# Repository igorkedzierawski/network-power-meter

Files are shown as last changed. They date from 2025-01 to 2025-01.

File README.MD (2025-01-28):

# Power Panel with Built-in Energy Analyzer based on ESP32

## Project Description
This project was realized as part of my engineering thesis at the Warsaw University of Technology. The device measures the voltage and current of connected devices. The measured data is transmitted from the device to a web application, where it is analyzed. In real-time, the application processes the gathered data and presents the electrical parameters and visualizations of the voltage and current waveforms to the user.

The device is controlled via the web application – measurements are read, results are visualized, and analysis is performed there. The operation is intuitive:
1. Connect the device to power.
2. Connect to it via Wi-Fi.
3. Connect the device you want to test.
4. Measurement results and analysis are available in the web interface.

The final result of the project is a ready-to-use IoT device.

## System Architecture
The project consists of three main components:

1. **Meter Controller** (ESP32 + measurement circuit) – responsible for Wi-Fi connectivity, menu handling, and managing the measurement circuit.
2. **Backend (ESP32 HTTP/WebSocket Server)** – allows control of the device via HTTP endpoints and fast transmission of measurement results via WebSocket.
3. **Frontend (Angular)** – the web application responsible for controlling the meter, analyzing the received data, and presenting both calculated values and waveform visualizations.
4. **PCB Design** – connects all physical components of the meter control board.

## Web Interface Functionality
- **View Electrical Parameters and Harmonic Analysis** – real-time display of measurement results for voltage, current, and power, as well as THD coefficient and harmonic analysis.
- **Waveform Visualization** – shows measured waveforms on a virtual oscilloscope.
- **Measurement Channel and System Parameter Configuration** – allows setting different channels and adjusting device parameters.
- **Trigger Selection and Analysis Window Width Adjustment** – stabilizes waveform drawing and adjusts measurement precision.
- **Meter Calibration** – adjusts calibration coefficients and selects network frequency (50/60Hz).

## Repository Structure
- **smm-esp32** – Source code for ESP32 (C, ESP-IDF)
- **smm-frontend** – Web application (Angular, TypeScript)
- **smm-pcb** – PCB design (KiCad)

## Device Photos

### Final Device
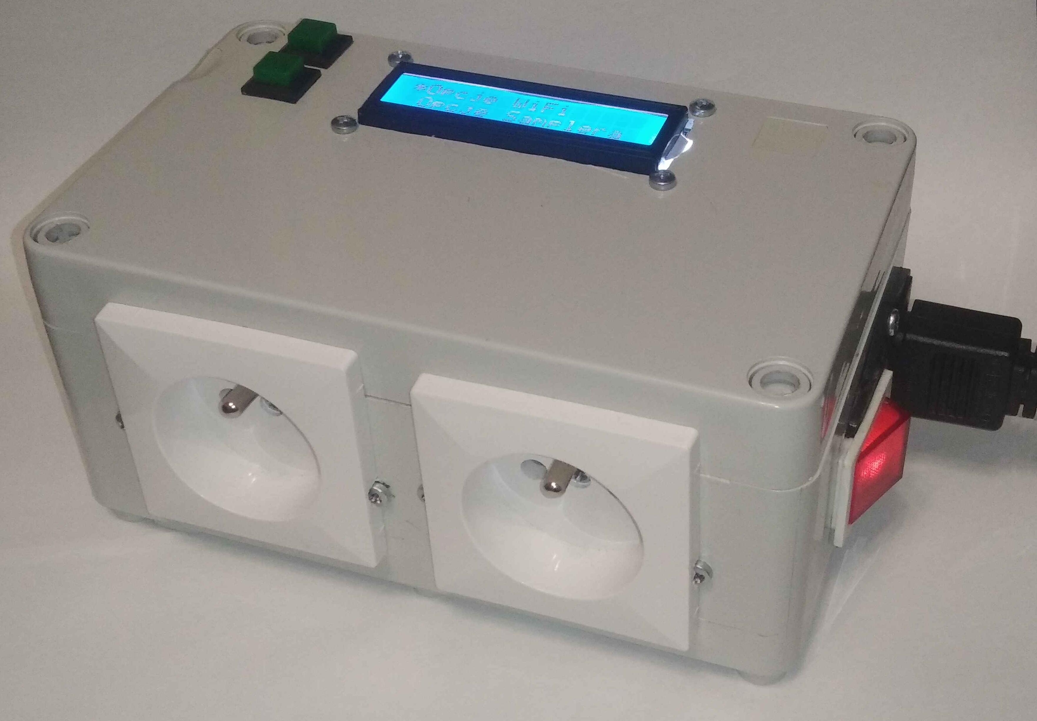
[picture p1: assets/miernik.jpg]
Meter


### Meter Control Board PCB
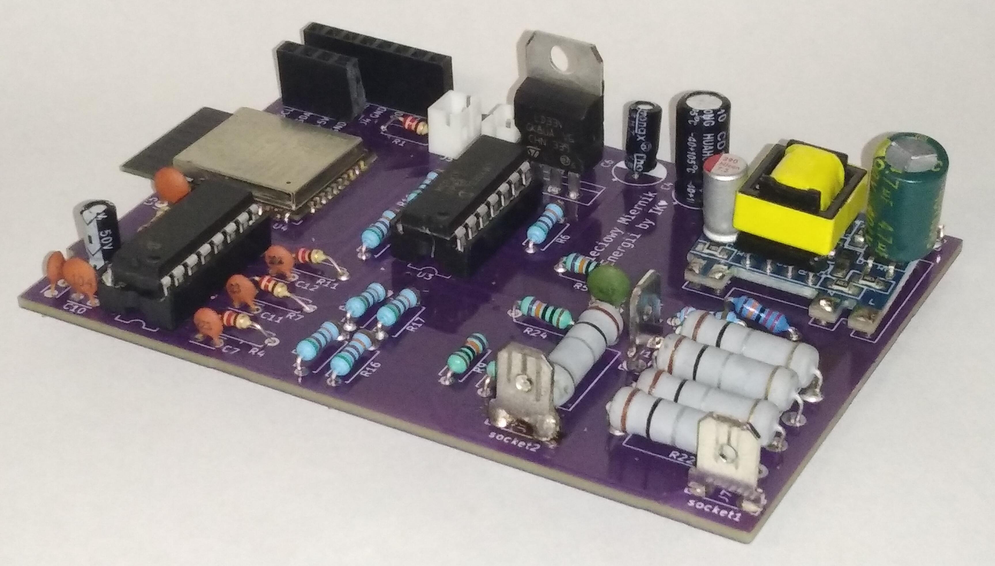
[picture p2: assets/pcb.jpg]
PCB


### Web Interface in Use
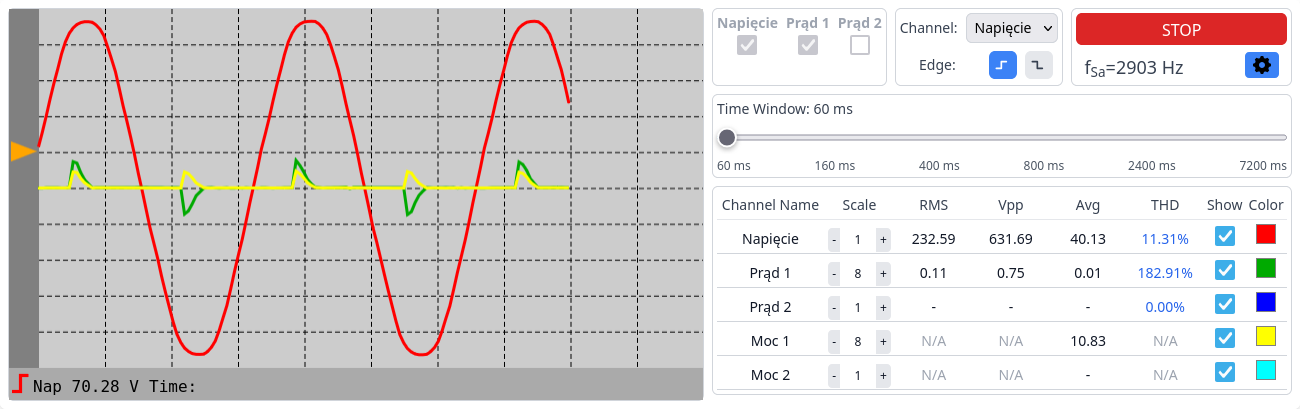
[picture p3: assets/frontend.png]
Interface


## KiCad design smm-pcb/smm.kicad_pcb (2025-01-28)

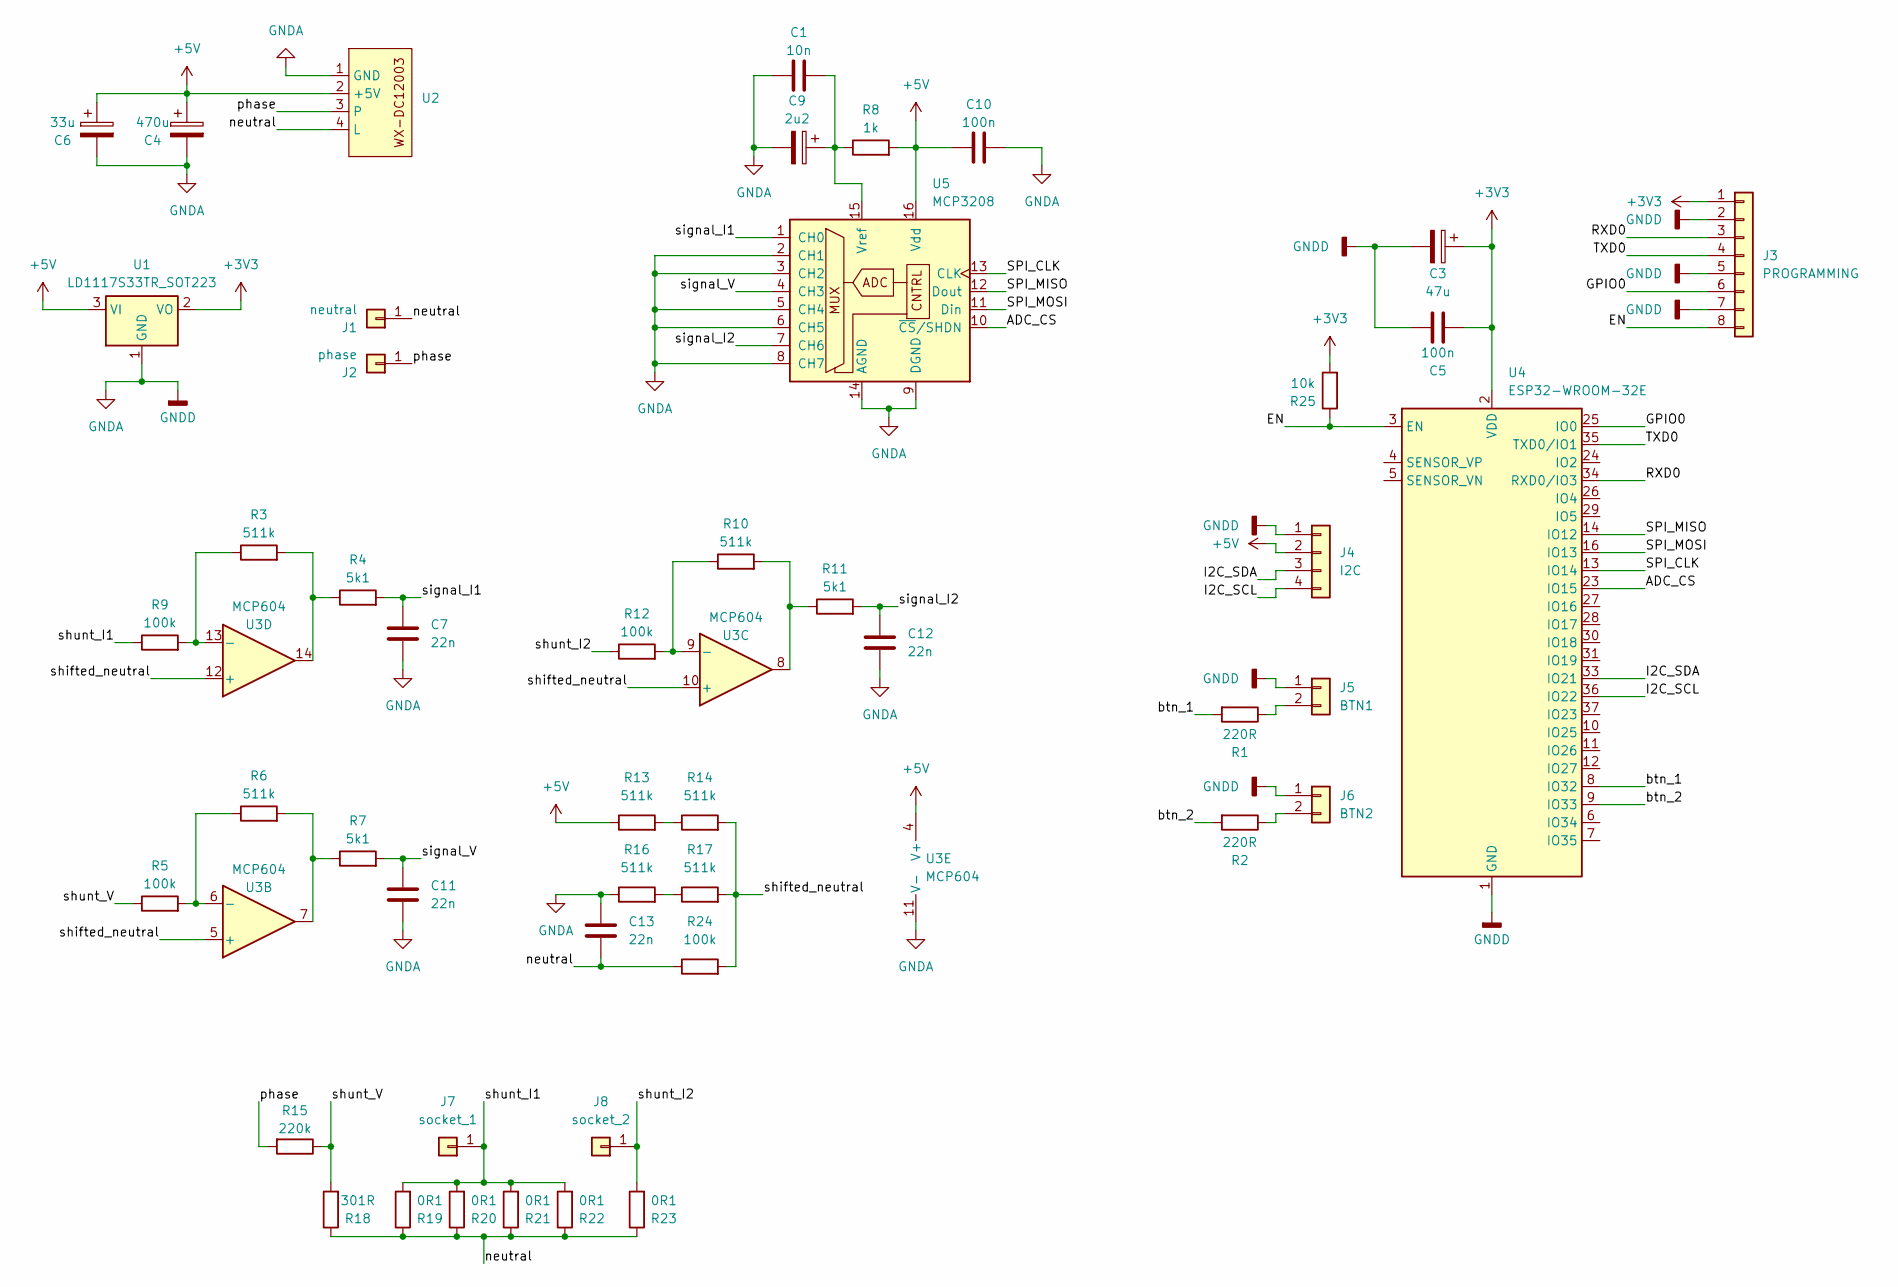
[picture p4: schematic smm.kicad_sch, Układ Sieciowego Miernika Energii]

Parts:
C1: 10n; C_Disc_D3.0mm_W2.0mm_P2.50mm
C3: 47u; CP_Radial_D6.3mm_P2.50mm
C4: 470u; CP_Radial_D6.3mm_P2.50mm
C5, C10: 100n; C_Disc_D3.0mm_W2.0mm_P2.50mm
C6: 33u; CP_Radial_D6.3mm_P2.50mm
C7, C11, C12, C13: 22n; C_Disc_D3.0mm_W2.0mm_P2.50mm
C9: 2u2; CP_Radial_D6.3mm_P2.50mm
J1: neutral; spade_connector_6.3_0.8
J2: phase; spade_connector_6.3_0.8
J3: PROGRAMMING; PinHeader_1x08_P2.54mm_Vertical
J4: I2C; PinHeader_1x04_P2.54mm_Vertical
J5: BTN1; PinHeader_1x02_P2.00mm_Vertical
J6: BTN2; PinHeader_1x02_P2.00mm_Vertical
J7: socket_1; spade_connector_6.3_0.8
J8: socket_2; spade_connector_6.3_0.8
R1, R2: 220R; R_Axial_DIN0207_L6.3mm_D2.5mm_P7.62mm_Horizontal
R3, R6, R10, R13, R14, R16, R17: 511k; R_Axial_DIN0207_L6.3mm_D2.5mm_P7.62mm_Horizontal
R4, R7, R11: 5k1; R_Axial_DIN0207_L6.3mm_D2.5mm_P7.62mm_Horizontal
R5, R9, R12, R24: 100k; R_Axial_DIN0207_L6.3mm_D2.5mm_P7.62mm_Horizontal
R8: 1k; R_Axial_DIN0207_L6.3mm_D2.5mm_P7.62mm_Horizontal
R15: 220k; R_Axial_DIN0207_L6.3mm_D2.5mm_P7.62mm_Horizontal
R18: 301R; R_Axial_DIN0207_L6.3mm_D2.5mm_P7.62mm_Horizontal
R19, R20, R21, R22, R23: 0R1; R_Axial_DIN0414_L11.9mm_D4.5mm_P15.24mm_Horizontal
R25: 10k; R_Axial_DIN0207_L6.3mm_D2.5mm_P7.62mm_Horizontal
U1: LD1117S33TR_SOT223; TO-220-3_Vertical
U2: WX-DC12003
U3: MCP604; DIP-14_W7.62mm
U4: ESP32-WROOM-32E; ESP32-WROOM-32D
U5: MCP3208; DIP-16_W7.62mm

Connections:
+3V3: C3.1, C5.1, J3.1, R25.2, U1.2 (VO), U4.2 (VDD)
+5V: C4.1, C6.1, C10.1, J4.2, R8.2, R13.1, U1.3 (VI), U2.2 (+5V), U3.4 (V+), U5.16 (Vdd)
/ADC_CS: U4.23 (IO15), U5.10 (~CS/SHDN)
/EN: J3.8, R25.1, U4.3 (EN)
/GPIO0: J3.6, U4.25 (IO0)
/I2C_SCL: J4.4, U4.36 (IO22)
/I2C_SDA: J4.3, U4.33 (IO21)
/RXD0: J3.3, U4.34 (RXD0/IO3)
/SPI_CLK: U4.13 (IO14), U5.13 (CLK)
/SPI_MISO: U4.14 (IO12), U5.12 (Dout)
/SPI_MOSI: U4.16 (IO13), U5.11 (Din)
/TXD0: J3.4, U4.35 (TXD0/IO1)
/btn_1: R1.2, U4.8 (IO32)
/btn_2: R2.2, U4.9 (IO33)
/neutral: C13.2, J1.1, R18.1, R19.1, R20.1, R21.1, R22.1, R23.1, R24.1, U2.4 (L)
/phase: J2.1, R15.2, U2.3
/shifted_neutral: R14.2, R17.2, R24.2, U3.5 (+), U3.10 (+), U3.12 (+)
/shunt_I1: J7.1, R9.1, R19.2, R20.2, R21.2, R22.2
/shunt_I2: J8.1, R12.1, R23.2
/shunt_V: R5.1, R15.1, R18.2
/signal_I1: C7.1, R4.2, U5.1 (CH0)
/signal_I2: C12.1, R11.2, U5.7 (CH6)
/signal_V: C11.1, R7.2, U5.4 (CH3)
GNDA: C1.1, C3.2, C4.2, C5.2, C6.2, C7.2, C9.2, C10.2, C11.2, C12.2, C13.1, J3.2, J3.5, J3.7, J4.1, J5.1, J6.1, R16.1, U1.1 (GND), U2.1 (GND), U3.11 (V-), U4.1 (GND), U4.15 (GND), U4.38 (GND), U4.39 (GND), U5.2 (CH1), U5.3 (CH2), U5.5 (CH4), U5.6 (CH5), U5.8 (CH7), U5.9 (DGND), U5.14 (AGND)
unnamed: J5.2, R1.1
unnamed: J6.2, R2.1
unnamed: R3.2, R4.1, U3.14
unnamed: R6.2, R7.1, U3.7
unnamed: R10.2, R11.1, U3.8
unnamed: R13.2, R14.1
unnamed: R16.2, R17.1
unnamed: R5.2, R6.1, U3.6 (-)
unnamed: R10.1, R12.2, U3.9 (-)
unnamed: R3.1, R9.2, U3.13 (-)
unnamed: C1.2, C9.1, R8.1, U5.15 (Vref)

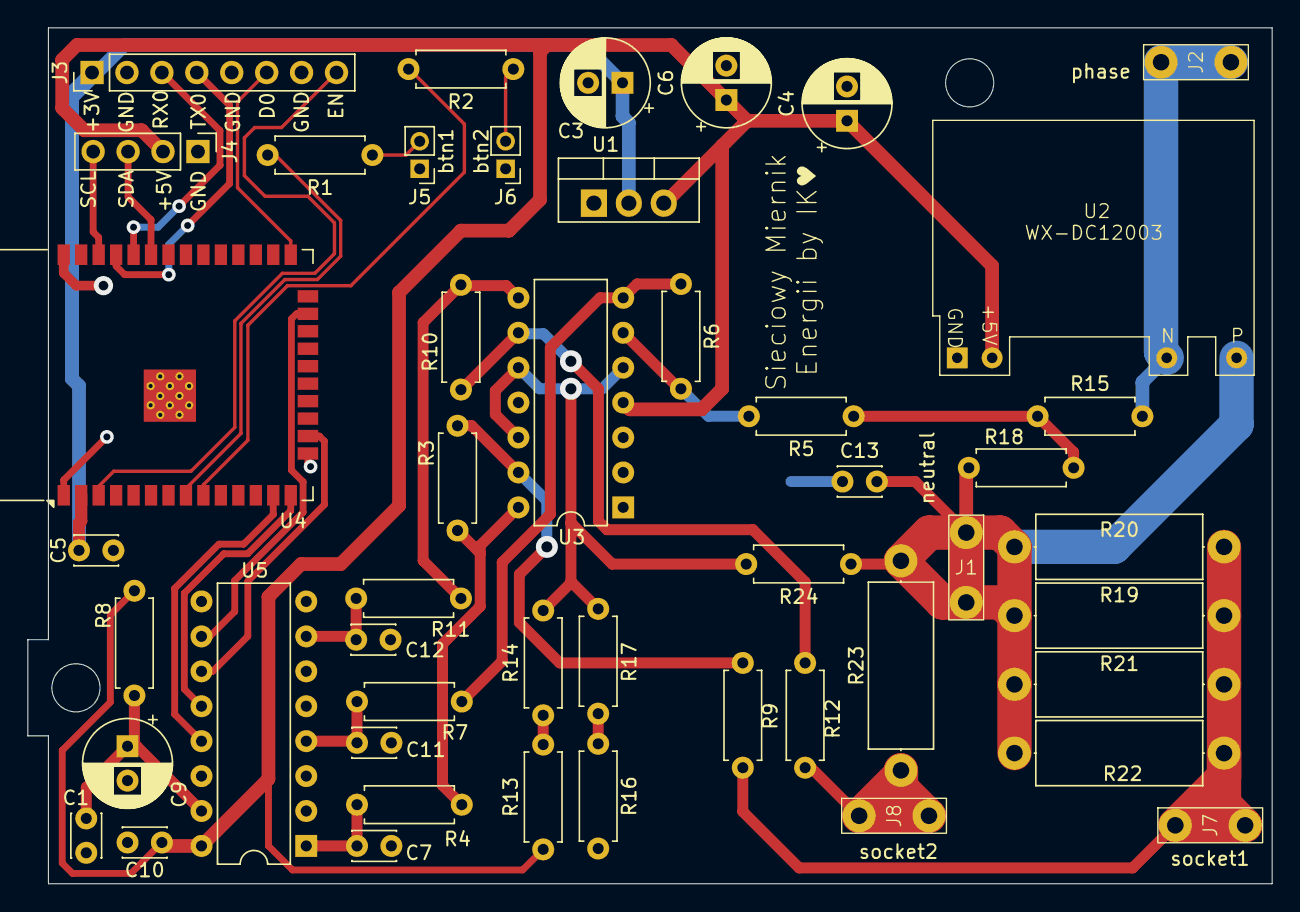
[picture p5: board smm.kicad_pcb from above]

Board: 2 copper layers, 90.5 x 62.2 mm, 48 parts (0 on the bottom side), 35 nets.

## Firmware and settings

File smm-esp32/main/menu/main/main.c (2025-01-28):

#include "main.h"
#include "../../wifimgr/menu.h"

#include "akdmenu.h"

akdmenu_menu_t root = akdmenu_decl_root_menu();

akdmenu_menu_t *menu_main_create(void) {
    akdmenu_menu_append(&root, wifimgr_menu_main_wifi_create());
    // akdmenu_menu_append(&root, akdmenu_any_as_item(menu_main_wifi_create()));
    akdmenu_menu_append(&root, menu_main_sampler_create());
    akdmenu_menu_rewind(&root);
    return &root;
}

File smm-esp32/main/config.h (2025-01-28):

#ifndef _SMM_CONFIG_H
#define _SMM_CONFIG_H

#define SMM_CONFIG_HSPI_MISO_PIN 12
#define SMM_CONFIG_HSPI_MOSI_PIN 13
#define SMM_CONFIG_HSPI_CLK_PIN 14

#define SMM_CONFIG_MCP3208_HOST_ID HSPI_HOST
#define SMM_CONFIG_MCP3208_CS_PIN 15
#define SMM_CONFIG_MCP3208_CLK_FREQ_HZ 6000000

#define SMM_CONFIG_I2C_NUM_0_SDA_PIN 21
#define SMM_CONFIG_I2C_NUM_0_SCL_PIN 22
#define SMM_CONFIG_I2C_NUM_0_CLK_FREQ_HZ 100000
#define SMM_CONFIG_I2C_NUM_0_SDA_PULLUP_EN GPIO_PULLUP_ENABLE
#define SMM_CONFIG_I2C_NUM_0_SCL_PULLUP_EN GPIO_PULLUP_ENABLE

#define SMM_CONFIG_LCD_I2C_PORT I2C_NUM_0
#define SMM_CONFIG_LCD_ADDRESS 0x27
#define SMM_CONFIG_LCD_COLUMNS 16
#define SMM_CONFIG_LCD_ROWS 2

#define SMM_CONFIG_MENU_COLUMNS SMM_CONFIG_LCD_COLUMNS
#define SMM_CONFIG_MENU_ROWS SMM_CONFIG_LCD_ROWS

#define SMM_CONFIG_BUTTONS_BTN_UP_PIN 32
#define SMM_CONFIG_BUTTONS_BTN_DOWN_PIN 33
#define SMM_CONFIG_BUTTONS_SHORT_PRESS_TIME 150
#define SMM_CONFIG_BUTTONS_LONG_PRESS_TIME 750

#endif

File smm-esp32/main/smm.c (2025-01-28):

#include "freertos/FreeRTOS.h"
#include "freertos/task.h"

#include <stdio.h>
#include <string.h>

#include "esp_log.h"
#include "esp_check.h"
#include "esp_err.h"
#include "driver/gpio.h"
#include "driver/spi_master.h"

#include "lcd.h"
#include "mcp3208.h"
#include "initsys.h"
#include "akdmenu.h"
#include "sampler/sampler.h"

#include "iot_button.h"
#include "textmenu.h"
#include "menu/menu.h"
#include "wifimgr/wifimgr.h"
#include "esp_mac.h"
#include "nvs_flash.h"

#include "esp_spiffs.h"
#include "calibration/calibration.h"

static const char *TAG = "SMM";

lcd_handle_t lcd_handle;
spi_device_handle_t mcp_handle;

void render_line(uint8_t line) {
    akdmenu_host_t *hostptr = menu_get_host();
    char buf[17];
    for (uint8_t i = 0; i < hostptr->rows; i++) {
        uint8_t buf_index = hostptr->line_dbuf_origin + i;
        akdmenu_item_t *item = hostptr->line_dbuf[buf_index];
        bool selected = (buf_index == hostptr->rows), non_null = (item != NULL);
        const char *format = non_null && selected ? "*%-16s" : " %-16s";
        const char *text = non_null ? item->meta.text : "??";
        snprintf(buf, sizeof(buf), format, text);
        lcd_set_cursor(&lcd_handle, 0, i);
        lcd_write_str(&lcd_handle, buf);
    }
}

void init_all(void) {
    ESP_ERROR_CHECK(smm_initsys_init_hspi());
    ESP_ERROR_CHECK(smm_initsys_init_i2c_num_0());

    ESP_ERROR_CHECK(smm_initsys_init_netif());
    ESP_ERROR_CHECK(smm_initsys_init_default_event_loop());
    ESP_ERROR_CHECK(smm_initsys_init_nvs());
    ESP_ERROR_CHECK(smm_initsys_init_wifi());

    ESP_ERROR_CHECK(smm_initsys_init_adc(&mcp_handle));
    ESP_ERROR_CHECK(smm_initsys_init_lcd(&lcd_handle));

    ESP_ERROR_CHECK(smm_initsys_init_spiffs());

    ESP_ERROR_CHECK(smm_initsys_init_sampler(&mcp_handle));

    ESP_ERROR_CHECK(smm_initsys_init_webserver());

    ESP_ERROR_CHECK(smm_initsys_init_menu(render_line));
    textmenu_init();
    ESP_ERROR_CHECK(smm_initsys_init_buttons());
}

void app_main(void) {
    init_all();
    if (!smm_initsys_check_all_initialized()) {
        ESP_LOGE(TAG, "not every subsystem was initialized");
        return;
    }

    lcd_clear_screen(&lcd_handle);
    lcd_no_cursor(&lcd_handle);
    lcd_backlight(&lcd_handle);

    ESP_LOGI("TAG", "DONE[%d] => %d", i++, (int)wifimgr_set_credentials(WIFI_IF_AP, "MiernikMocy", "12345678"));

    ESP_ERROR_CHECK(wifimgr_set_if_enabled(WIFI_IF_AP, true));

    char ipbuffer[46] = {0};
    wifimgr_get_ip(WIFI_IF_STA, ipbuffer, 45);

    ESP_ERROR_CHECK_WITHOUT_ABORT(sampler_select_channels(3));
}
